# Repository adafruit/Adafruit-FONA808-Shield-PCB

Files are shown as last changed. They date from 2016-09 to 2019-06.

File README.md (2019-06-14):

## Adafruit FONA808 Shield PCB

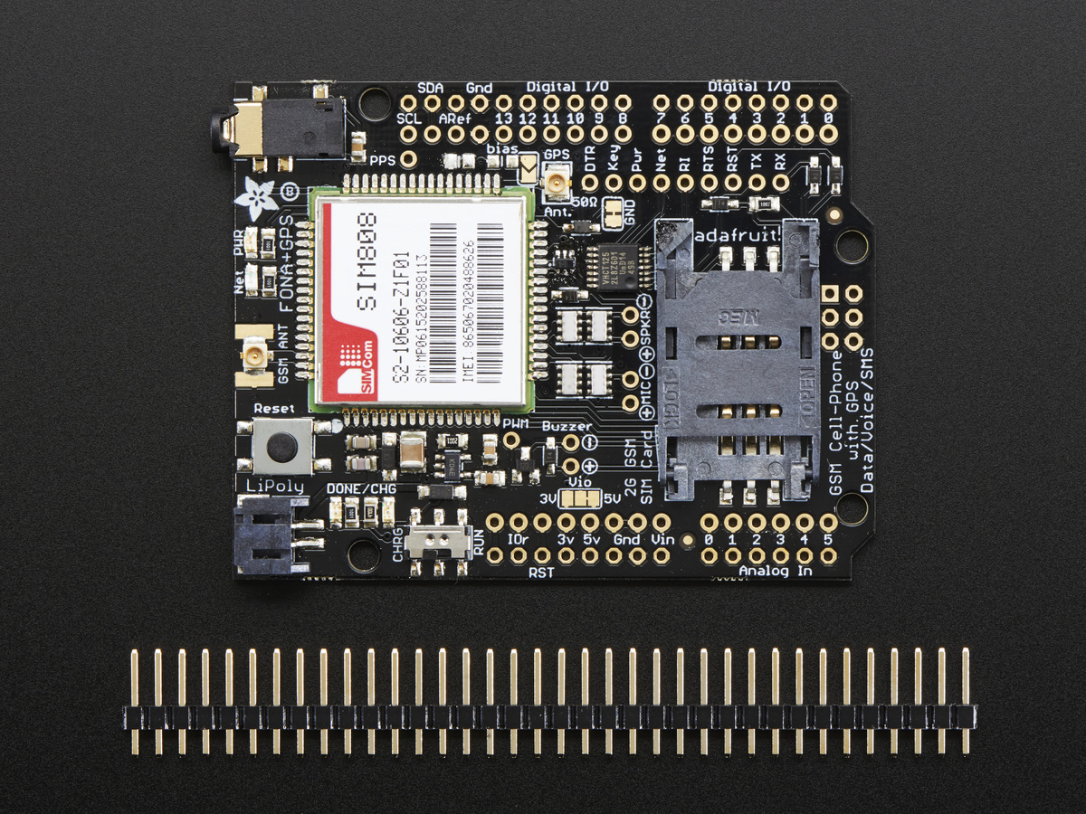
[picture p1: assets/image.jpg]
<a href="http://www.adafruit.com/products/2636"><br/>
Click here to purchase one from the Adafruit shop</a>

PCB files for the Adafruit FONA808 Shield. Format is EagleCAD schematic and board layout
* https://www.adafruit.com/products/2636

### DESCRIPTION
Cellular + GPS tracking, all in one, for your Arduino? Oh yes! Introducing Adafruit FONA 808 GSM + GPS Shield, an all-in-one cellular phone module with that lets you add location-tracking, voice, text, SMS and data to your project, in Arduino shield format for easy use.

If you want a version without GPS, check out the FONA 800 Shield [here](https://www.adafruit.com/product/2468).

If you don't need the shield format, we also have this is a petite breakout [here](https://www.adafruit.com/product/2542).

If you just want a plain FONA, [click here](https://www.adafruit.com/product/1946).

This shield fits right over your Arduino or compatible. At the heart is a powerful GSM cellular module (we use the latest SIM808) with integrated GPS. This module can do just about everything

- Quad-band 850/900/1800/1900MHz - connect onto any global GSM network with any 2G SIM (in the USA, T-Mobile is suggested)
- Fully-integrated GPS (MT3337 chipset with -165 dBm tracking sensitivity) that can be controlled and query over the same serial port
- Make and receive voice calls using a headset or an external 32Ω speaker + electret microphone
- Send and receive SMS messages
- Send and receive GPRS data (TCP/IP, HTTP, etc.)
- PWM/Buzzer vibrational motor control
- AT command interface with "auto baud" detection

### License

Adafruit invests time and resources providing this open source design, please support Adafruit and open-source hardware by purchasing products from [Adafruit.com](https://www.adafruit.com)!

Designed by Adafruit Industries. 

Creative Commons Attribution, Share-Alike license, check license.txt for more information All text above must be included in any redistribution - see license.txt for more information.

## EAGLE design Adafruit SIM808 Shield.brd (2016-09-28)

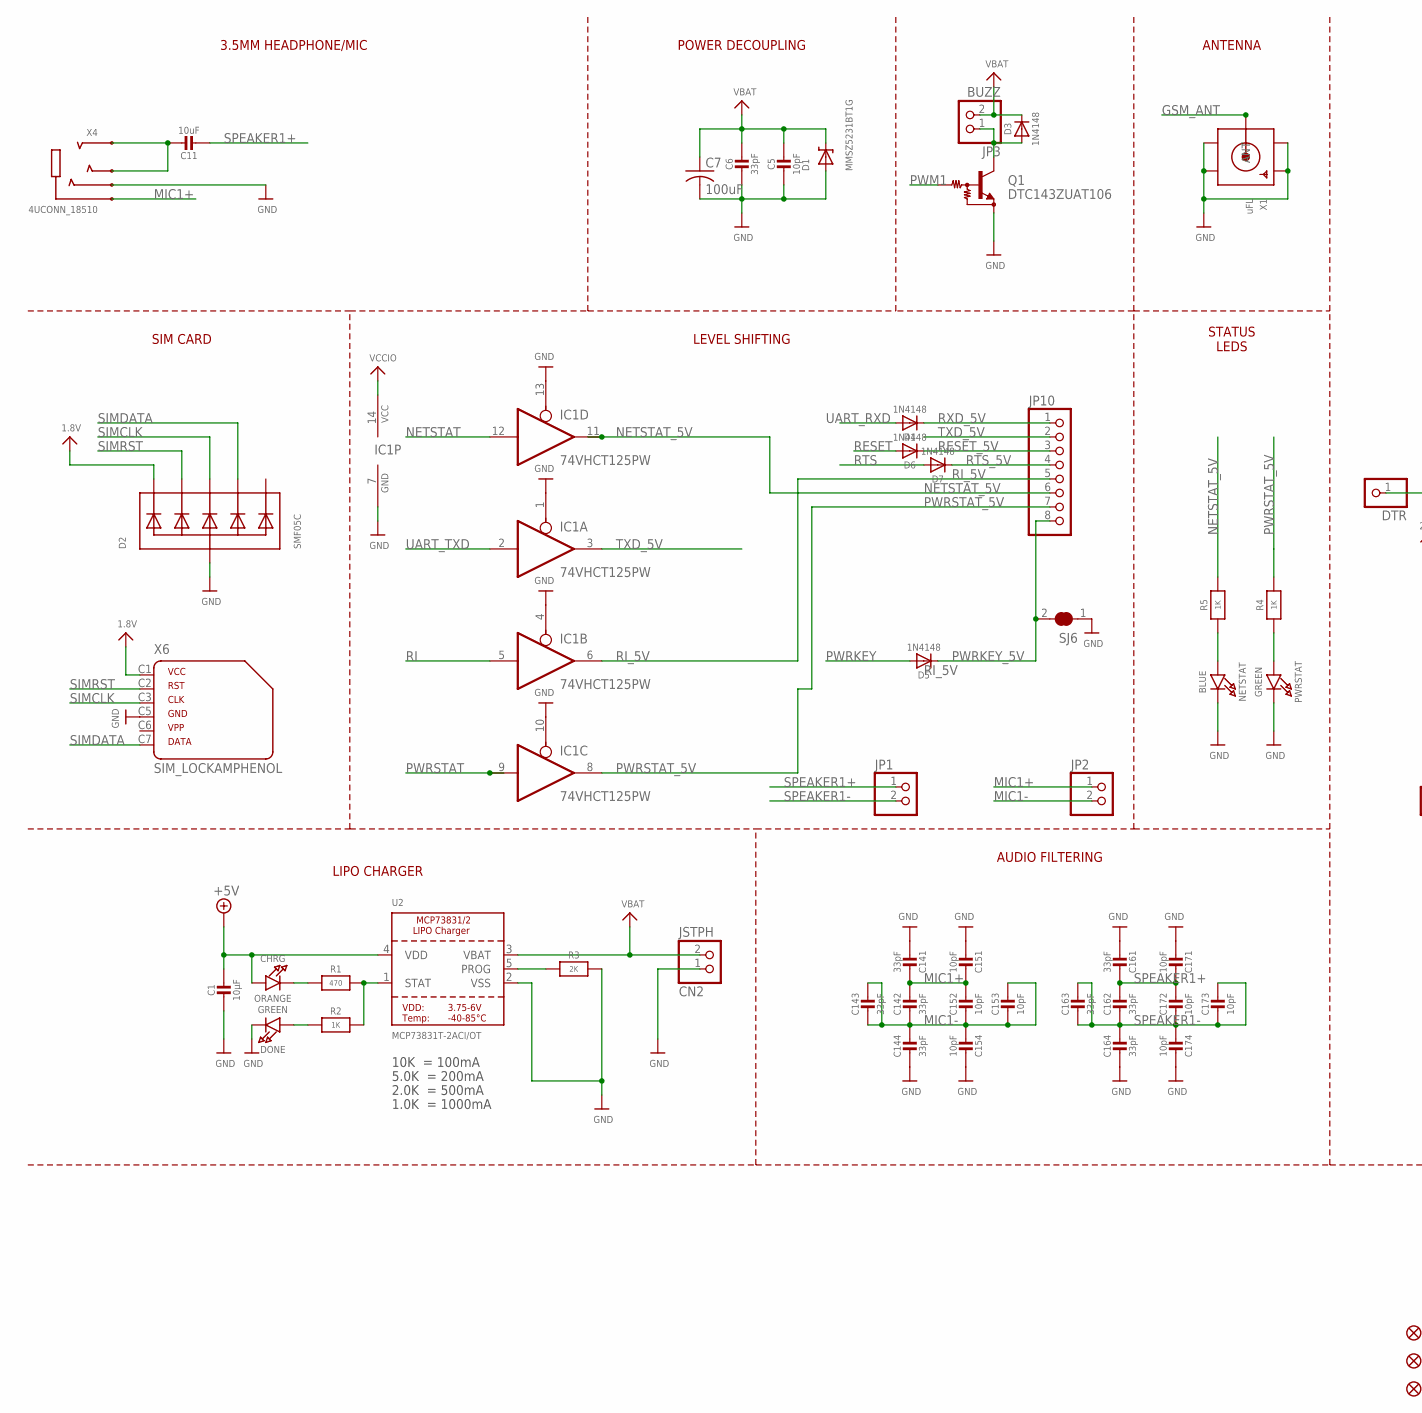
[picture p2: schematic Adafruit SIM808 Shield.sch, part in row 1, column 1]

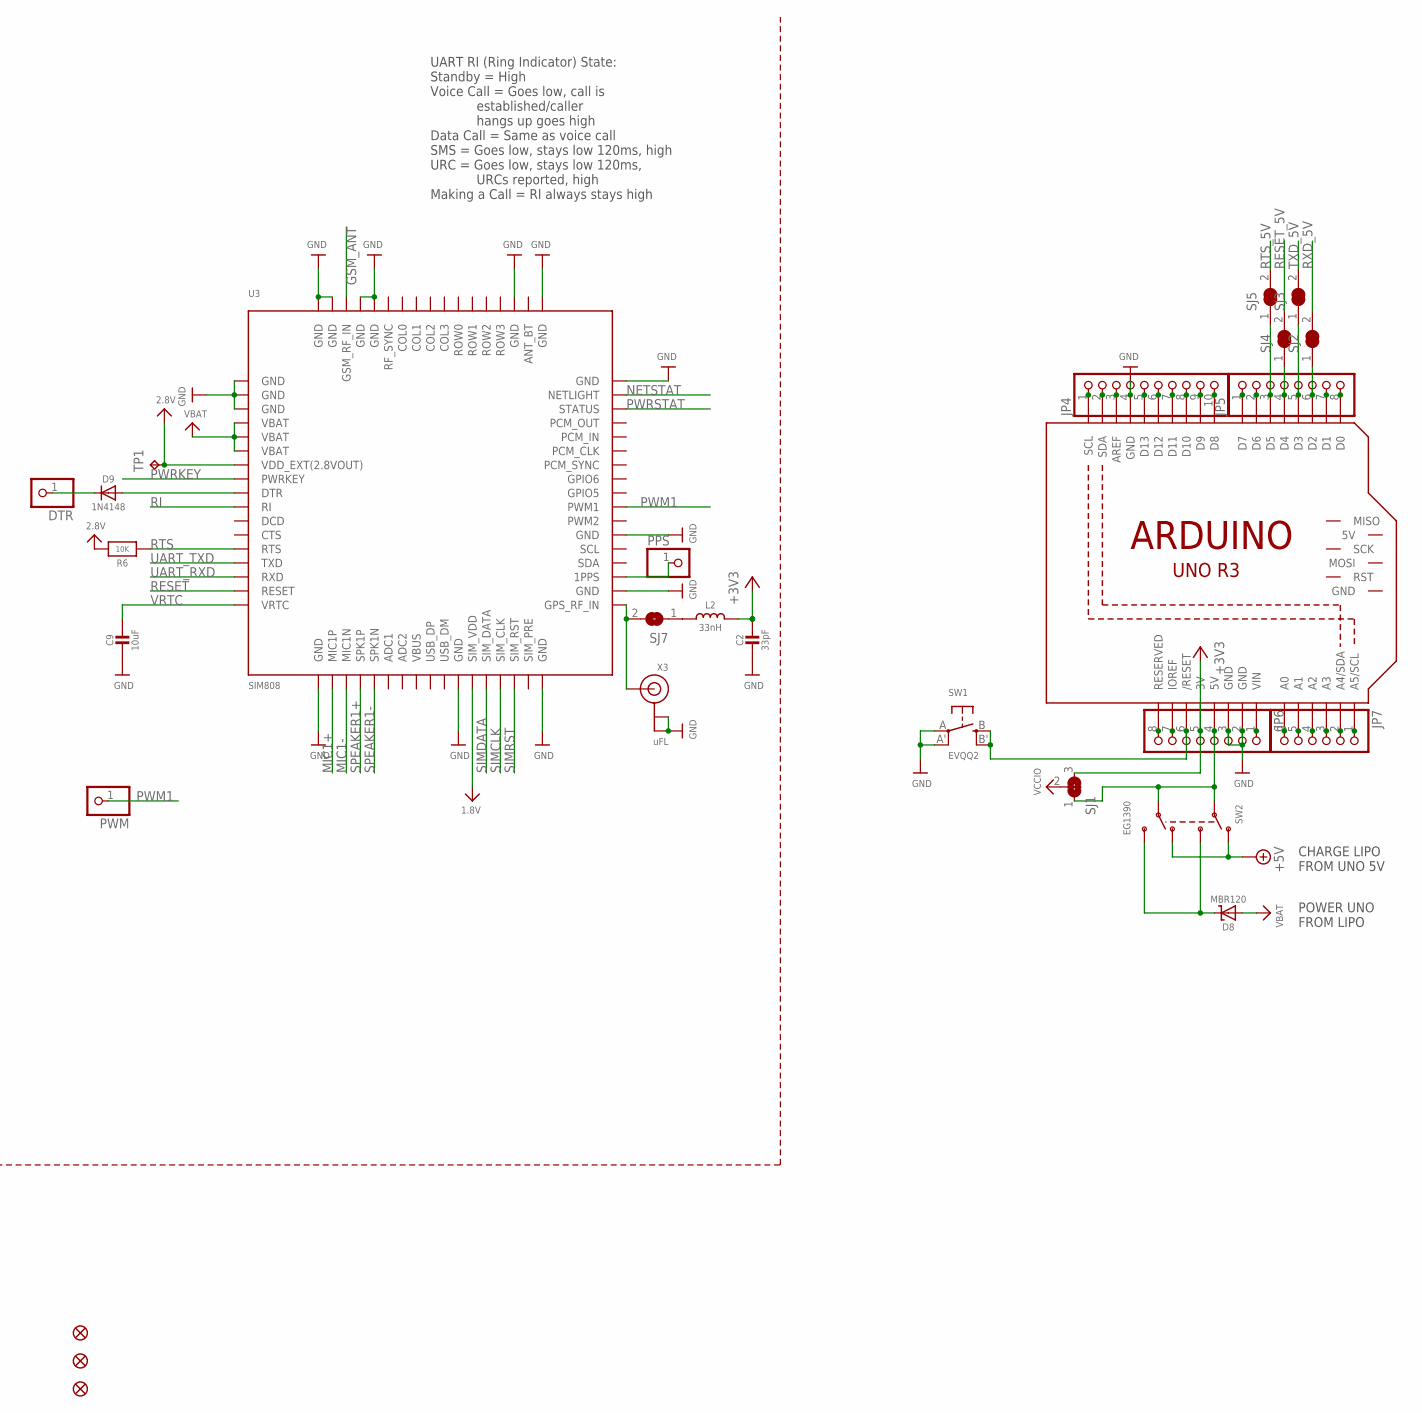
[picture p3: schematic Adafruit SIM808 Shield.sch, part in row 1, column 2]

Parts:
C1: 10µF; 0805-NO
C2, C6: 33pF; 0805-NO
C5: 10pF; 0805-NO
C7: 100uF; C1210
C9, C11: 10uF; 0805-NO
C14, C16: 33pF; RESPACK_4X0603
C15, C17: 10pF; RESPACK_4X0603
CHRG: ORANGE; CHIPLED_0805_NOOUTLINE
CN2: JSTPH; JSTPH2
D1: MMSZ5231BT1G; SOD-123
D2: SMF05C; SOT363
D3, D4, D5, D6, D7, D9: 1N4148; SOD-323
D8: MBR120; SOD-123
DONE: GREEN; CHIPLED_0805_NOOUTLINE
DTR: PINHD-1X1CB; 1X01-CLEANBIG
FID1, FID2, FID3: FIDUCIAL""; FIDUCIAL_1MM
IC1: 74VHCT125PW; TSSOP14
JP1, JP2: HEADER-1X2ROUND; 1X02_ROUND
JP3: BUZZ; 1X02_ROUND
JP4: HEADER-1X1070MIL; 1X10_ROUND70
JP5, JP6: HEADER-1X876MIL; 1X08_ROUND_76
JP7: HEADER-1X676MIL; 1X06_ROUND_76
JP10: HEADER-1X870MIL; 1X08_ROUND_70
L2: 33nH; _0805MP
M1: ARDUINO_R3_ICSP_NODIM; ARDUINOR3_ICSP_NODIM
NETSTAT: BLUE; CHIPLED_0805_NOOUTLINE
PPS: PINHD-1X1CB; 1X01-CLEANBIG
PWM: PINHD-1X1CB; 1X01-CLEANBIG
PWRSTAT: GREEN; CHIPLED_0805_NOOUTLINE
Q1: DTC143ZUAT106; SC59-BEC
R1: 470; 0805-NO
R2, R4, R5: 1K; 0805-NO
R3: 2K; 0805-NO
R6: 10K; 0805-NO
SJ1: SOLDERJUMPER_2WAY; SOLDERJUMPER_2WAY_OPEN_NOPASTE
SJ2, SJ3, SJ4, SJ5, SJ6: SOLDERJUMPER_CLOSED; SOLDERJUMPER_CLOSEDWIRE
SJ7: SOLDERJUMPER; SOLDERJUMPER_ARROW_NOPASTE
SW1: EVQQ2; EVQ-Q2
SW2: EG1390
TP1: TPTP11R; TP11R
U2: MCP73831T-2ACI/OT; SOT23-5
U3: SIM808; SIM900_SMT
X1: uFL; SMA_EDGELAUNCH_UFL
X3: uFL; U.FL
X4: 4UCONN_18510
X6: SIM_LOCKAMPHENOL; C707_10M006_512_2

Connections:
1.8V: D2.1 (C1), U3.P$29 (SIM_VDD), X6.C1 (1)
2.8V: R6.2, TP1.TP, U3.P$7 (VDD_EXT(2.8VOUT))
5V: JP6.4, M1.5V, SJ1.1, SW2.P1, SW2.P2
+3V3: C2.1, JP6.5, L2.2, M1.3V, SJ1.3
+5V: C1.1, CHRG.A, SW2.O1, SW2.O2, U2.4 (VDD)
A0: JP7.6, M1.A0
A1: JP7.5, M1.A1
A2: JP7.4, M1.A2
A3: JP7.3, M1.A3
A4: JP7.2, M1.A4 (A4/SDA)
A5: JP7.1, M1.A5 (A5/SCL)
AREF: JP4.3, M1.AREF
BUZZ-: D3.A, JP3.1, Q1.C
D0: JP5.8, M1.D0
D1: JP5.7, M1.D1
D2: JP5.6, M1.D2, SJ2.1
D3: JP5.5, M1.D3, SJ3.1
D4: JP5.4, M1.D4, SJ4.1
D5: JP5.3, M1.D5, SJ5.1
D6: JP5.2, M1.D6
D7: JP5.1, M1.D7
D8: JP4.10, M1.D8
D9: JP4.9, M1.D9
D10: JP4.8, M1.D10
D11: JP4.7, M1.D11
D12: JP4.6, M1.D12
D13: JP4.5, M1.D13
DTR_5V: D9.C, DTR.1
GND: C1.2, C2.2, C5.2, C6.2, C7.2, C9.2, C14.5 (2), C14.8 (2), C15.4 (1), C15.8 (2), C16.5 (2), C16.8 (2), C17.4 (1), C17.8 (2), CN2.1, D1.A, D2.2 (A), DONE.C, IC1.1 (OE), IC1.4 (OE), IC1.7 (GND), IC1.10 (OE), IC1.13 (OE), JP4.4, JP6.2, JP6.3, M1.GND, M1.GND@1 (GND), M1.GND@3 (GND), NETSTAT.C, PWRSTAT.C, Q1.E, R3.2, SJ6.1, SW1.A, SW1.A' (P1), U2.2 (VSS), U3.P$1 (GND), U3.P$2 (GND), U3.P$3 (GND), U3.P$18 (GND), U3.P$28 (GND), U3.P$34 (GND), U3.P$36 (GND), U3.P$40 (GND), U3.P$51 (GND), U3.P$52 (GND), U3.P$54 (GND), U3.P$64 (GND), U3.P$65 (GND), U3.P$67 (GND), U3.P$68 (GND), X1.GND@1 (GND1), X1.GND@2 (GND2), X1.GND@3 (GND3), X1.GND@4 (GND4), X3.1 (GND), X3.2 (GND), X4.4-INNER_SLEEVE (RING1), X6.C5 (4)
GPS_PPS: PPS.1, U3.P$37 (1PPS)
GSM_ANT: U3.P$66 (GSM_RF_IN), X1.P (ANT)
HP+: C11.1, X4.2-TIP (RING3), X4.3-OUTER_SLEEVE (RING2)
IOREF: JP6.7, M1.IOREF
MIC1+: C14.1, C14.2 (1), C15.1, C15.2 (1), JP2.1, U3.P$19 (MIC1P), X4.1-GND (TIP)
MIC1-: C14.3 (1), C14.4 (1), C14.6 (2), C14.7 (2), C15.3 (1), C15.5 (2), C15.6 (2), C15.7 (2), JP2.2, U3.P$20 (MIC1N)
unnamed: CHRG.C, R1.1
unnamed: R1.2, R2.2, U2.1 (STAT)
unnamed: SJ7.2, U3.P$35 (GPS_RF_IN), X3.3 (SIGNAL)
unnamed: PWRSTAT.A, R4.1
unnamed: R3.1, U2.5 (PROG)
unnamed: DONE.A, R2.1
unnamed: NETSTAT.A, R5.1
unnamed: D8.C, SW2.S1, SW2.S2
unnamed: L2.1, SJ7.1
unnamed: D9.A, U3.P$9 (DTR)
NC: JP6.8, M1.RESERVED
NETSTAT: IC1.12 (I), U3.P$50 (NETLIGHT)
NETSTAT_5V: IC1.11 (O), JP10.6, R5.2
PWM1: PWM.1, Q1.B, U3.P$42 (PWM1)
PWRKEY: D5.A, U3.P$8 (PWRKEY)
PWRKEY_5V: D5.C, JP10.8, SJ6.2
PWRSTAT: IC1.9 (I), U3.P$49 (STATUS)
PWRSTAT_5V: IC1.8 (O), JP10.7, R4.2
RESET: D6.A, U3.P$16 (RESET)
RESET_5V: D6.C, JP10.3, SJ4.2
RI: IC1.5 (I), U3.P$10 (RI)
RI_5V: IC1.6 (O), JP10.5
RST: JP6.6, M1.RESET (/RESET), SW1.B (S), SW1.B' (S1)
RTS: D7.A, R6.1, U3.P$13 (RTS)
RTS_5V: D7.C, JP10.4, SJ5.2
RXD_5V: D4.C, JP10.1, SJ2.2
SCL: JP4.1, M1.SCL
SDA: JP4.2, M1.SDA
SIMCLK: D2.4 (C3), U3.P$31 (SIM_CLK), X6.C3 (3)
SIMDATA: D2.5 (C4), U3.P$30 (SIM_DATA), X6.C7 (6)
SIMRST: D2.3 (C2), U3.P$32 (SIM_RST), X6.C2 (2)
SPEAKER1+: C11.2, C16.1, C16.2 (1), C17.1, C17.2 (1), JP1.1, U3.P$21 (SPK1P)
SPEAKER1-: C16.3 (1), C16.4 (1), C16.6 (2), C16.7 (2), C17.3 (1), C17.5 (2), C17.6 (2), C17.7 (2), JP1.2, U3.P$22 (SPK1N)
TXD_5V: IC1.3 (O), JP10.2, SJ3.2
UART_RXD: D4.A, U3.P$15 (RXD)
UART_TXD: IC1.2 (I), U3.P$14 (TXD)
VBAT: C5.1, C6.1, C7.1, CN2.2, D1.C, D3.C, D8.A, JP3.2, U2.3 (VBAT), U3.P$4 (VBAT), U3.P$5 (VBAT), U3.P$6 (VBAT)
VBUS: U3.P$25 (VBUS)
VCCIO: IC1.14 (VCC), SJ1.2
VIN: JP6.1, M1.VIN
VRTC: C9.1, U3.P$17 (VRTC)

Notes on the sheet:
10K = 100mA
5.0K = 200mA
2.0K = 500mA
1.0K = 1000mA
UART RI (Ring Indicator) State: Standby = High Voice Call = Goes low, call is established/caller hangs up goes high Data Call = Same as voice call SMS = Goes low, stays low 120ms, high URC = Goes low, stays low 120ms, URCs reported, high Making a Call = RI always stays high
ANTENNA
POWER DECOUPLING
3.5MM HEADPHONE/MIC
SIM CARD
LEVEL SHIFTING
LIPO CHARGER
AUDIO FILTERING
STATUS LEDS
CHARGE LIPO FROM UNO 5V
POWER UNO FROM LIPO

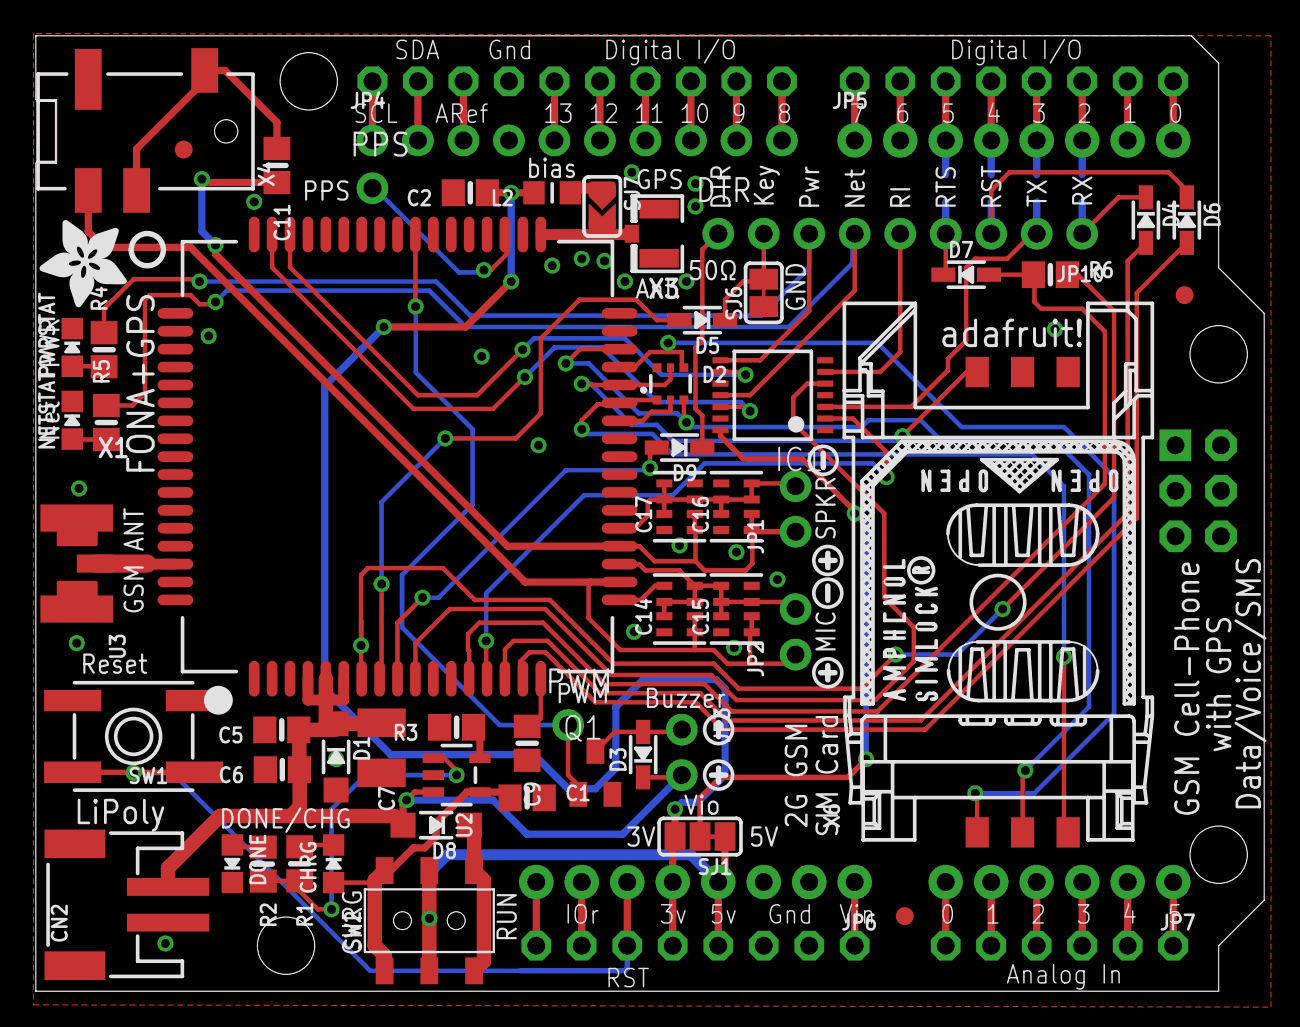
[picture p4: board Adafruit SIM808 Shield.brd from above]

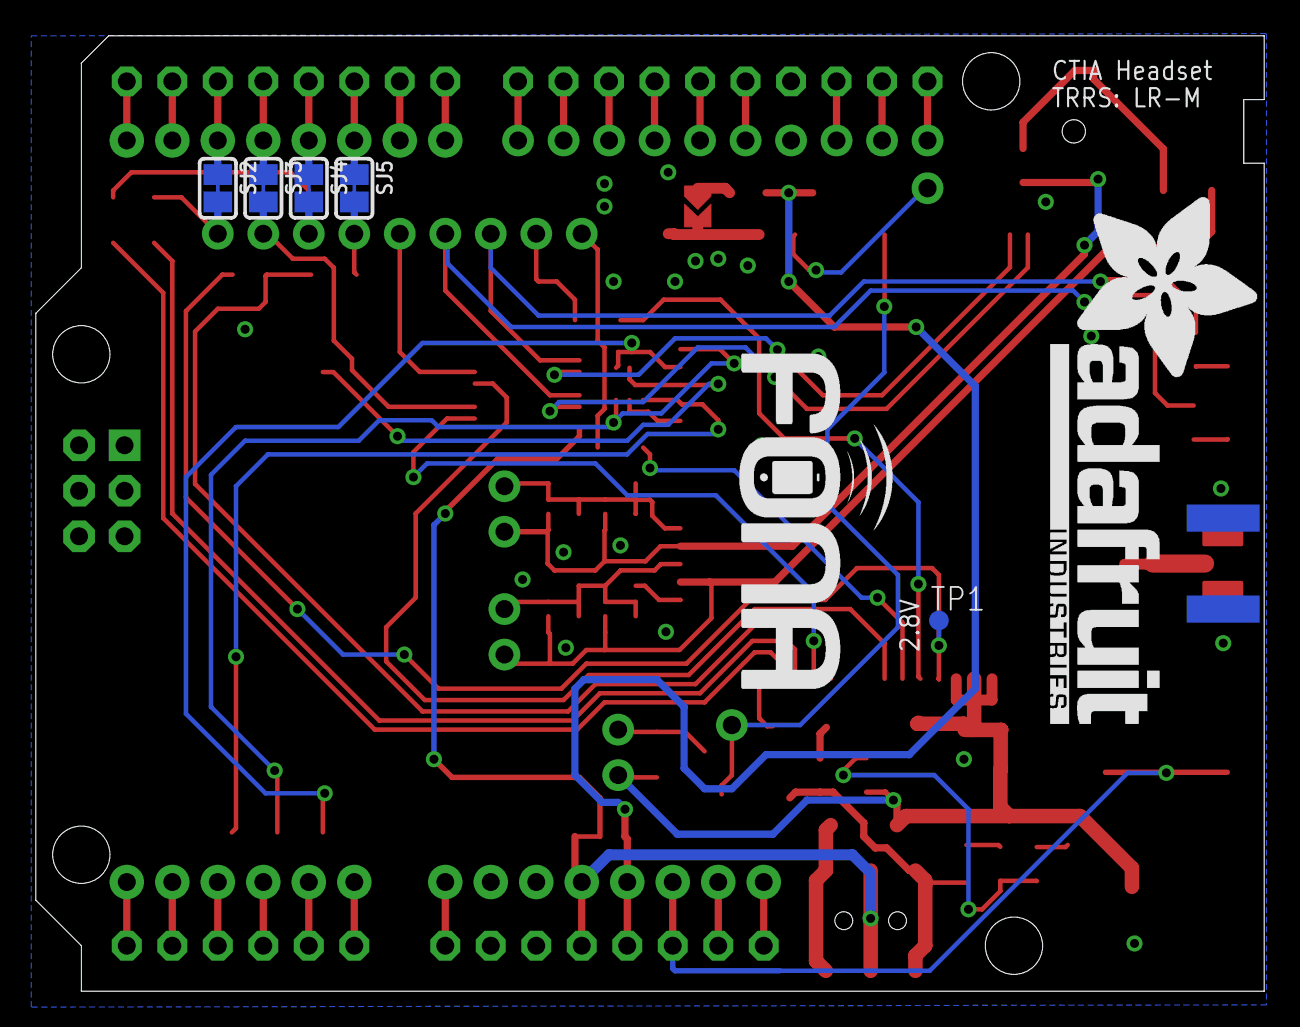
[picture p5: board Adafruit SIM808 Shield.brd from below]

Board: 2 copper layers, 68.6 x 53.3 mm, 75 parts (7 on the bottom side), 75 nets.

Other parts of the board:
U$2, U$20, U$35: SYMBOL_PLUS
U$25: ADAFRUIT_TEXT_30MM
U$26: FONA_LOGO
U$33, U$34, U$41: SYMBOL_MINUS
U$36: ADAFRUIT_5MM
U$64: PCBFEAT-REV-040

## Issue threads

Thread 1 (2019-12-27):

Modem stops working after enabling/disabling GPRS multiple times during day

jegjessing, 2019-12-27:
To save power I turned modem off and on during the day, using the "key" pin so it was just turned on when I needed it to.
Suddenly the modem could not register on network.
I changed it with another and changed the code so it enabled / disabled GPRS in hope that it might save some power there. Same result, I now had to change modem again.
And as soon as I change the modem, it works. I also tried the modems in another setup and they still would not work. So there is an issue with the modem being toggled several times a day.

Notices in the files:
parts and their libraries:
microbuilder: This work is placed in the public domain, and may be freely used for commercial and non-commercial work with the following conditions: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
